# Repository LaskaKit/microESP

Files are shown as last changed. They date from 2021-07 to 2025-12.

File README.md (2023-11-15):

# LaskaKit microESP with ESP32-C3

An incredibly powerful yet miniature board - microESP with the latest ESP32-C3 chip in the ESP32-C3-MINI module supporting Wi-Fi and Bluetooth connectivity and also has very low power consumption.

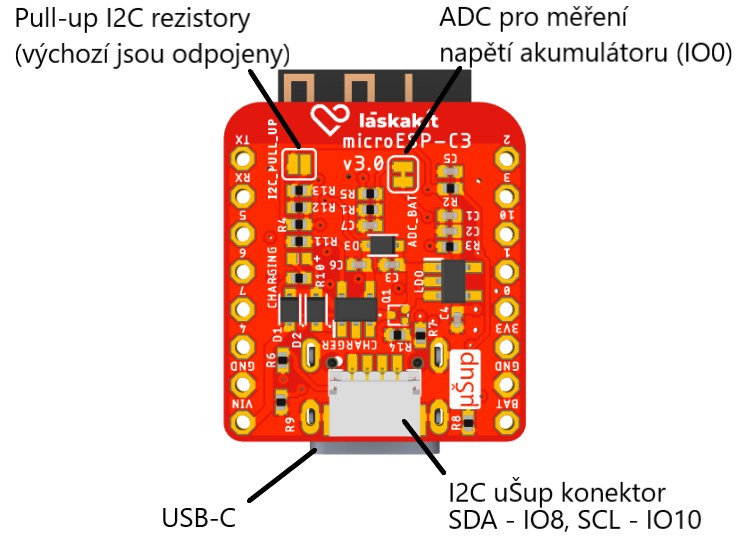
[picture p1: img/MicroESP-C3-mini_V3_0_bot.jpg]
Popis microESP_ESP32-C3_BOTTOM.jpg


PINOUT

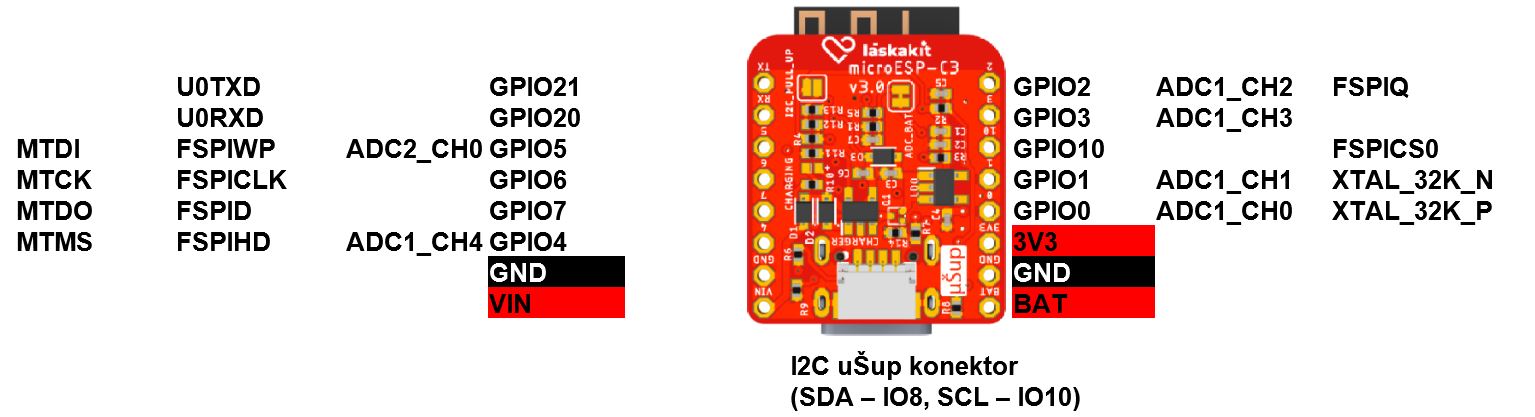
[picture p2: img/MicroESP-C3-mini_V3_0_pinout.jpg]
Pinout


As you can see above, the board includes a lot of things. Let's describe the boardy in details. 
The board is powered from Li-Pol battery what is charger through li-pol charger from solar panel. The recommended voltage of solar panel shall be 5V or 6V.

We put our versatile and safe μŠup connector where you can connect I2C sensors. The lock of connector is mounted inside the connector, so no worries, you can not damage the sensor because you can not turn over the connector.
The sensor what are useful for this board are [SHT40 (temperature and humidity)](https://www.laskakit.cz/laskakit-sht40-senzor-teploty-a-vlhkosti-vzduchu/) or [SCD41 (CO2, temperature, humidity](https://www.laskakit.cz/laskakit-scd41-senzor-co2--teploty-a-vlhkosti-vzduchu/). 
Moreover, we added GPIOs on both sides of board what you can use for what you want.

On the upper side, there are two solder bridges. First solder bridge is used for enabling of voltage measurement from battery. 
One is battery voltage measurement (connected to IO0) and the maximum input voltage is 5.8V (with 3.3V ADC reference voltage, R1 1M, R2 1.3M). 
The second solder bridge is used for connecting of I2C pull up resistors (SDA - IO8, SCL - IO10) to power supply (3.3V).

To program this miniature and very economical board, you need to connect a USB-C cable to your computer and switch the ESP32-C3 to bootloader mode with the following trick.
Connect the USB-C to the microESP and the computer.
Press and hold the FLASH button.
Press and release the RESET button.
Release the FLASH button.

This board is available on https://www.laskakit.cz/laskakit-microesp/

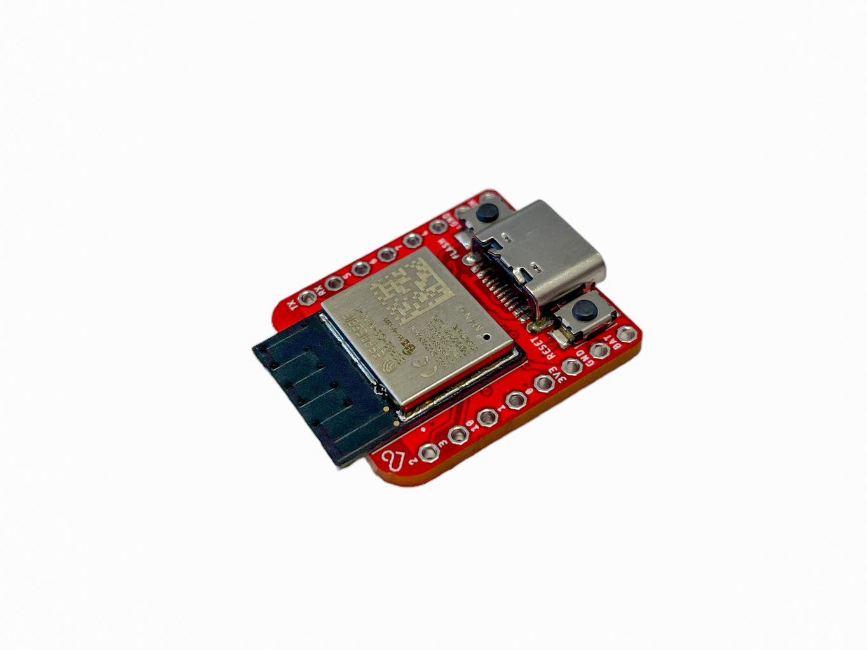
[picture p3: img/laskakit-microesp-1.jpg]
TOP

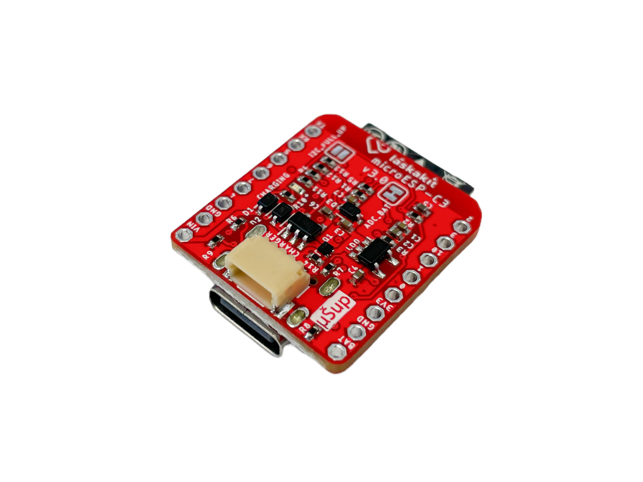
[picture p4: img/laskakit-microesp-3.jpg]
BOTTOM


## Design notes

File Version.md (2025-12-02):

### Version 3.2
- Fixed wrong IO number on top silkscreen, IO8 was "1"
#### Version 3.1
- LDO replaced for RT9080
- µŠup konnector moved a little bit inside
- I2C pullups deleted
- Some power optimisation
- LED Added on GPIO 4
#### Version 3.0
- Reworked version with new module ESP32-C3-MINI
#### Version 2.1
Adjusted resistor values in the resistance divider to 1M/1.3M, ADC max. input voltage stays the same.| Upraveny hodnoty rezistorů v odporovém děliči na 1M/1.3M, ADC max. vstupní napětí zůstává stejné.
#### Version 2.0
- Change ESP-12 to ESP32-C3 | Změněn modul ESP-12 na ESP32-C3
- Voltager devider GPIIO0 (Bat_ADC) changed to 100k/130k ADC max. input voltage is 4.335 V | Dělič napětí GPIIO0 (Bat_ADC) změněn na 100k/130k ADC max. vstupní napětí je 4.335 V
- Voltager devider GPIIO1 (Solar_ADC) changed to 1M/330k ADC max. input voltage is 9.874 V | Dělič napětí GPIIO1 (Solar_ADC) změněn na 1M/330k ADC max. vstupní napětí je 9.874 V
- Add 100nF capacitors to ADC inputs Bat_ADC and Solar_ADC | Přidány filtrační kondenzátory 100nF na ADC vstupy Bat_ADC a Solar_ADC
#### Version 1.0
- Initial | Počáteční

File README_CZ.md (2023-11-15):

# LaskaKit microESP s ESP32-C3

Neskutečně nabušená a přitom miniaturní deska - microESP s nejnovějším čipem ESP32-C3 v modulu ESP32-C3-MINI podporující Wi-Fi i Bluetooth konektivitu a navíc má i velmi malou vlastní spotřebu. 

Popis microESP_ESP32-C3_BOTTOM.jpg

PINOUT

Pinout

Jak můžeš vidět na obrázku výše, na desce je toho opravdu hodně. Deska se napájí z připojeného akumulátoru, který může být nabíjen přes integrovaný nabíjecí kontrolér ze solárního panelu. Jmenovité napětí solárního panelu doporučujeme 5V nebo 6V. 

Na desku jsme přidali i náš μŠup konektor, ke kterému můžeš velmi pohodlně a bezpečně připojit nejrůznější I2C čidla. Konektor zajišťuje bezpečnost připojení díky vestavěnému zámku v konektoru. 
Čidla, která se hodí k této vývojové desce jsou například [SHT40 (čidlo teploty a vlhkosti)](https://www.laskakit.cz/laskakit-sht40-senzor-teploty-a-vlhkosti-vzduchu/) nebo [SCD41 (čidlo CO2, teploty, vlhkosti](https://www.laskakit.cz/laskakit-scd41-senzor-co2--teploty-a-vlhkosti-vzduchu/). 
Ale i přesto, že jsme tam dali konektor na I2C čidlo, využili jsme prostor ještě k přidání dalších GPIO po stranách modulu.
Vyvedli jsme i RX a TX sběrnice UART, takže pokud máš nějaké čidlo komunikující skrze UART, není problém ho s microESP použít. 

Na horní straně se ještě nachází dva pájecí mosty. Jeden je určený pro měření napětí akumulátoru (výstup za děličem napětí akumulátoru je připojen na IO0). Rezistor R1 je 1M, R2 je 1.3M, maximální vstupní napětí (při 3,3V ADC referenci) je 5,8V. 
Poslední pájecí most je připojení pull-up rezistorů na I2C sběrnici (SDA - IO8, SCL - IO10).

K programování této miniaturní a velmi úsporné desky potřebuješ připojit USB-C kabel k počítači a přepnout ESP32-C3 do bootloader režimu, což provedeš následujícím trikem.
Připoj USB-C do microESP a počítače.
Zmáčkni a drž tlačítko FLASH.
Zmáčkni a uvolni tlačítko RESET.
Uvolni tlačítko FLASH.

Tato deska je dostupná na https://www.laskakit.cz/laskakit-microesp/

TOP
BOTTOM

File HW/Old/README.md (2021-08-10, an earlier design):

# LaskaKit microESP

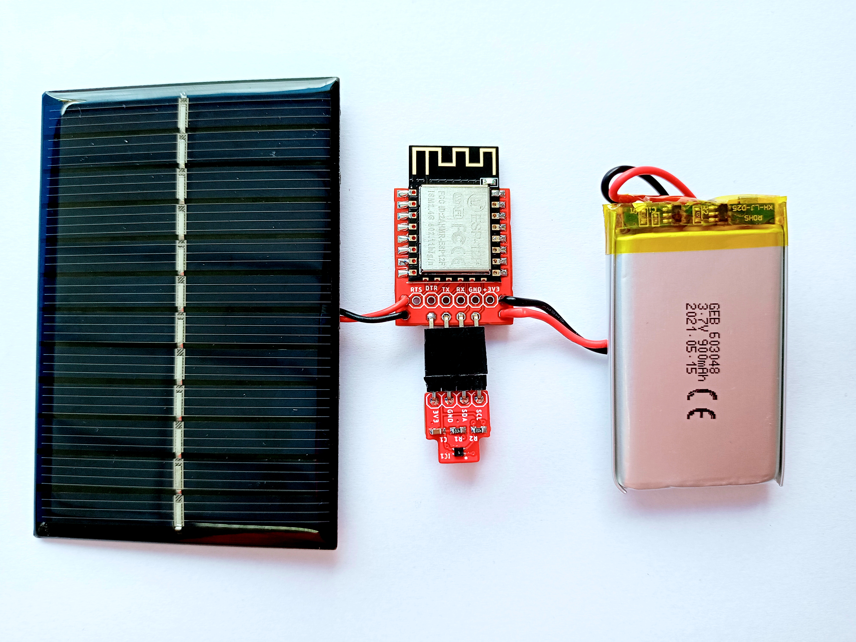
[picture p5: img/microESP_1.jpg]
microESP with solar panel


We would like to introduce the smallest evaluation board - [LaskaKit microESP](https://www.laskarduino.cz/laskakit-microesp/). The footprint is compatible with ESP12 or ESP07. It depends on you what you prefer to assemble. 
The dimension of PCB is only 24x21.5mm and the weight is 4g. The evaluation board includes - input of Li-ion battery, charging IC, 3.3V regulator with low quiescent current, input for solar panel and also connector with I2C bus.

## Layout

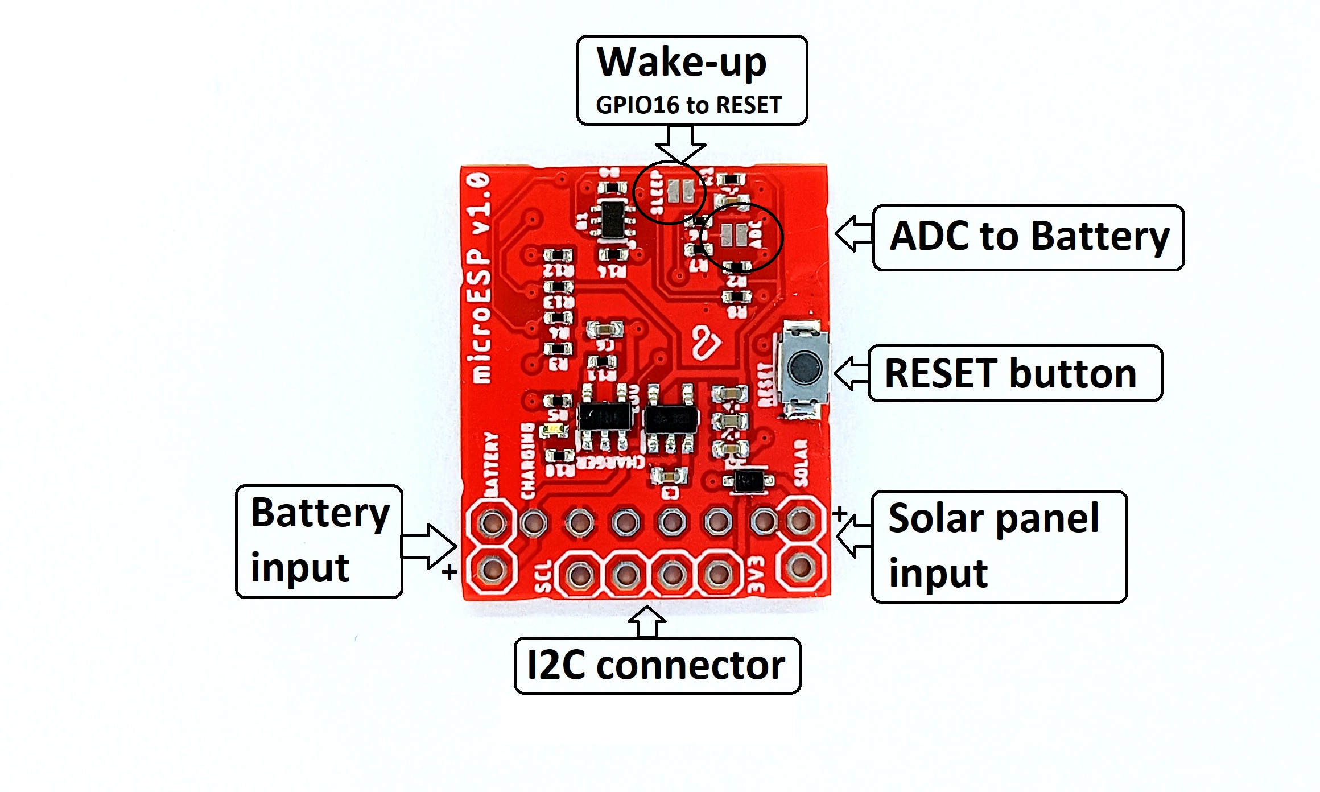
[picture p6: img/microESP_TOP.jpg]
TOP of microESP


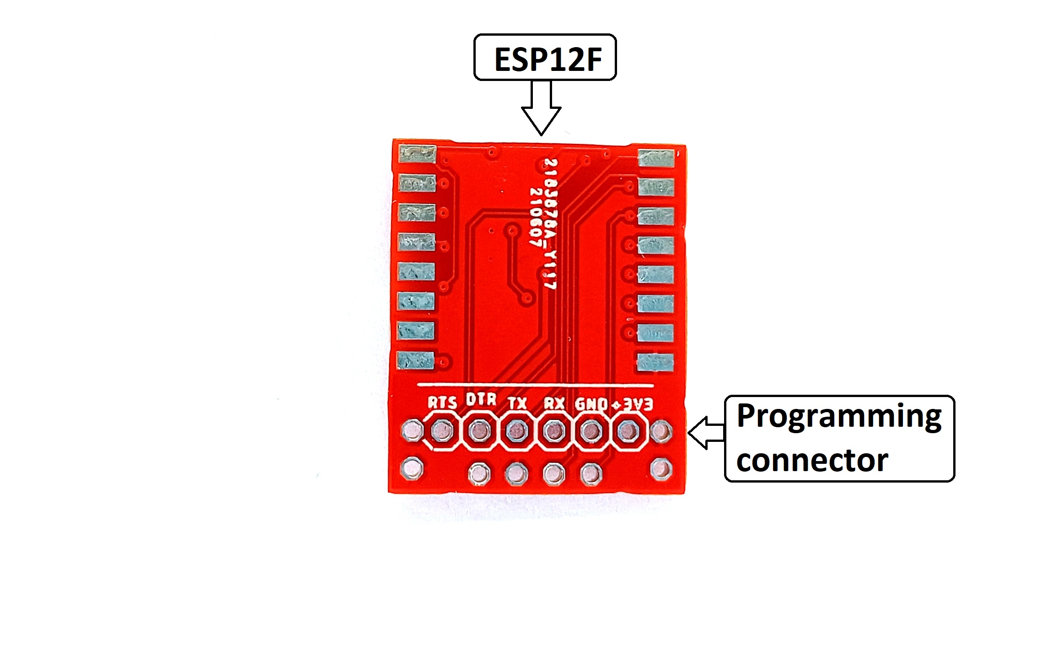
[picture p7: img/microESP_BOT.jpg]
BOTTOM of microESP


## Solar panel

The [TP4054](https://www.laskarduino.cz/toppower-tp4054-nabijecka-li-ion-clanku--0-4a--sot-23-5/) is used as charging IC, the maximum input voltaga is 10V hence the nominal voltage of solar panel shall be 5V, maximum 6V.

The charging current is defined by R11 resistor and the current is set to 400 mA.

## 3.3V regulator

We used HT7833 as main 3.3V regulator. The main advantage of this regulator is very low quiescentcurrent, typicaly 4 uA. 
Thanks to this regulator and the design of board, the overall current in deepsleep is only 22 uA.

## Programmer

We have own USB-UART programmer with CH340 IC, [LaskaKit CH340 programmer](https://www.laskarduino.cz/laskakit-ch340-programmer-usb-c--microusb--uart/). You can connect this programmer to your laptop through microUSB or USB-C cabel. 
The pinout of programmer is compatible with microESP. The programmer automatically switches the ESP8266 to bootloader mode and after the uploading of code, the ESP is automatically reset. 

## Another features

[LaskaKit microESP](https://www.laskarduino.cz/laskakit-microesp/) contains I2C connector for our temperature/humidity SHT4x/SHT3x module, buti t is not necessary to use only our module. You may directly use for example this module with [SHT31 module](https://www.laskarduino.cz/senzor-teploty-a-vlhkosti-vzduchu-sht30/), and indirectly [sensor of pressure, temperature and humidity BME280](https://www.laskarduino.cz/arduino-senzor-tlaku--teploty-a-vlhkosti-bme280/), [infrared sensor MLX90615](https://www.laskarduino.cz/arduino-infracerveny-teplomer-mlx90615/) or [GY-21 HTU21D sensor of temperature and humidity](https://www.laskarduino.cz/gy-21-htu21d-senzor-teploty-a-vlhkosti/).

Moreover there are reset button, solder bridge between GPIO16 and reset (to enable the wake up from deepsleep) and also there is voltage divider what is connected to battery and ADC. 
The maximum measured voltage is 4.3V what is enough for measuring of Li-ion battery.

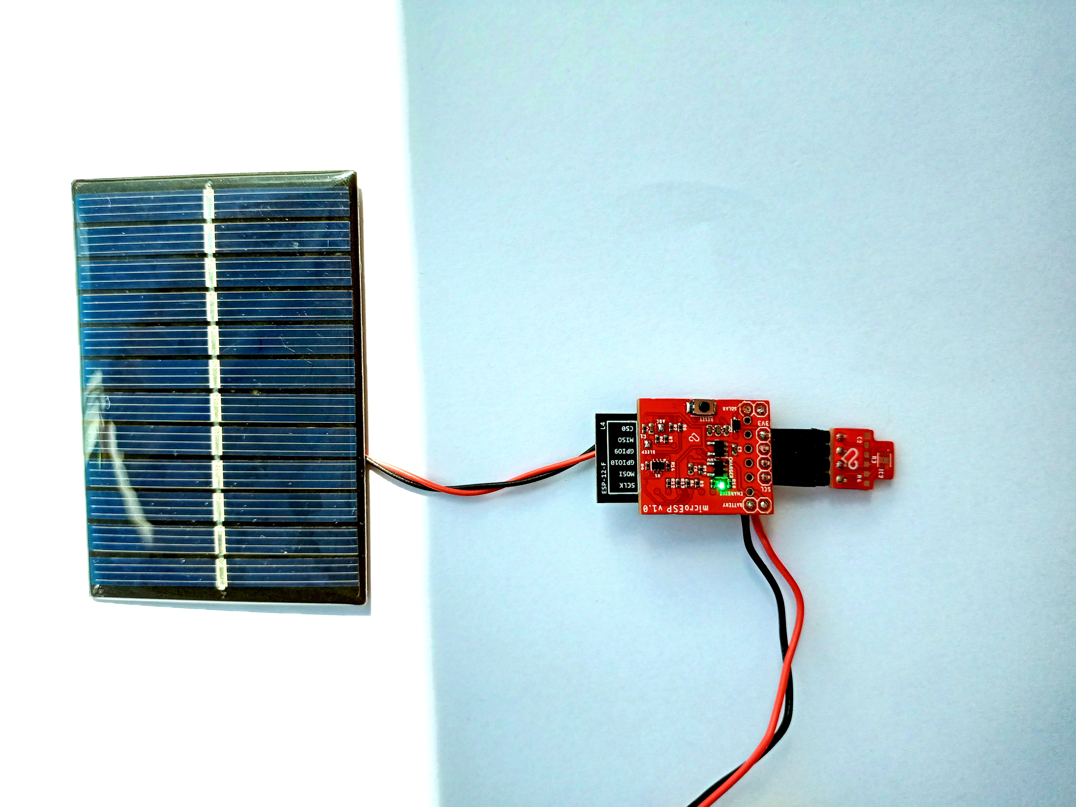
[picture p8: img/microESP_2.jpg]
microESP with solar panel


## Demo

We created a demo with our microESP, what you can see on the picture above.
The charging is indicated by LED on board, the sensor module [Temp-HumSensor-SHTxx](https://github.com/LaskaKit/Temp-HumSensor-SHTxx) may be directly connected to the main board. 

The example is available on [our github repository](https://github.com/LaskaKit/microESP/tree/main/examples). IN this example, ESP12 (which we soldered) reads the current temperature and humidity from SHT40 and send to Serial monitor.

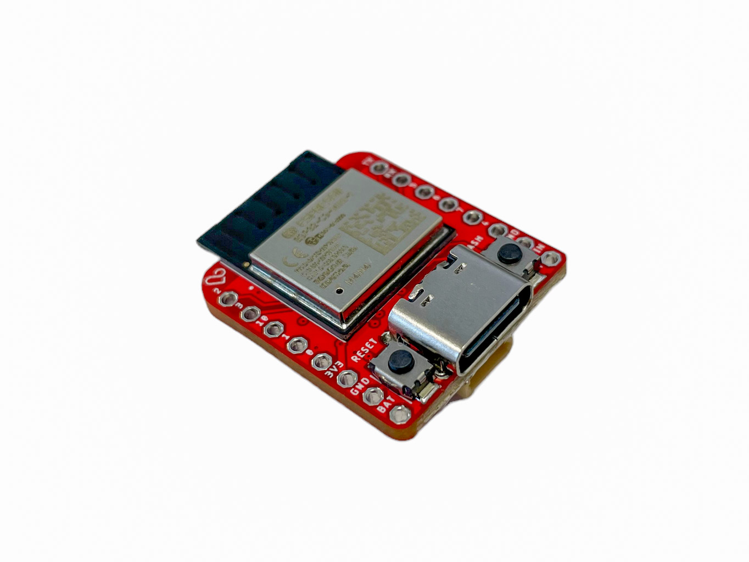
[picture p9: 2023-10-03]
img/laskakit-microesp-2.jpg

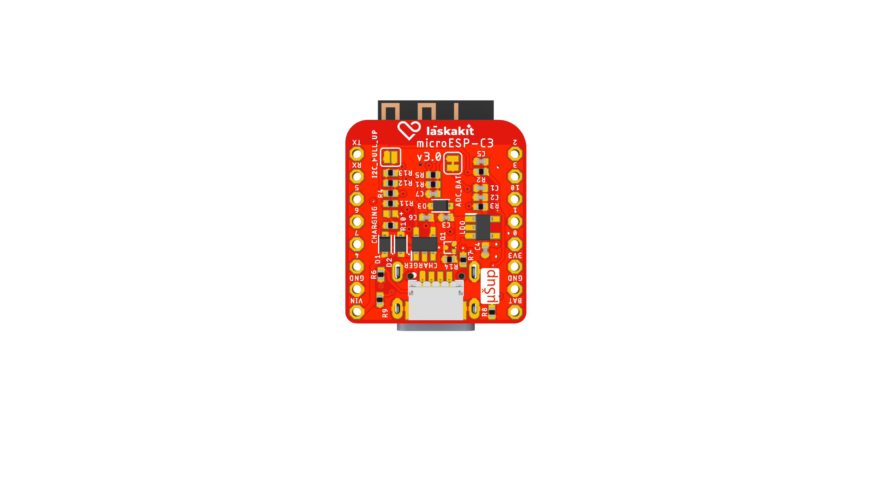
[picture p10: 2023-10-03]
img/MicroESP-C3-mini_back.png

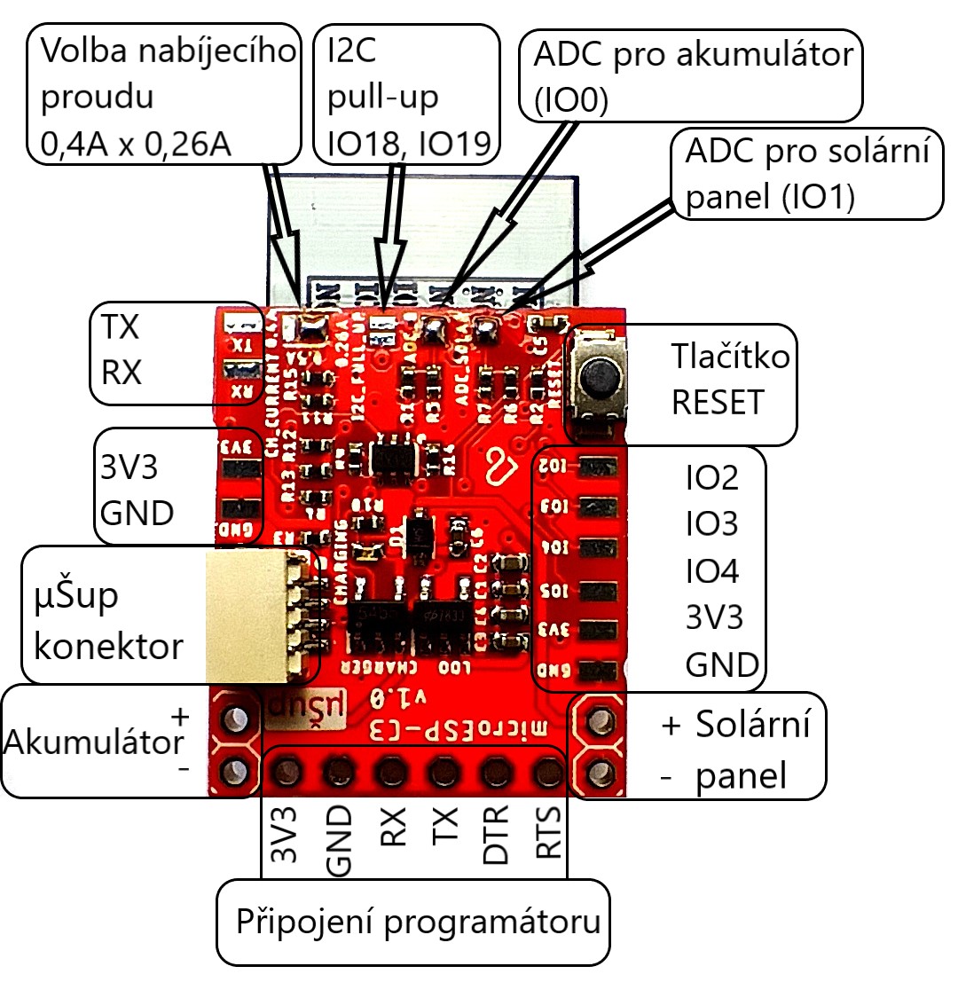
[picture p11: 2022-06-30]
img/microESP_ESP32-C3_BOTTOM.jpg

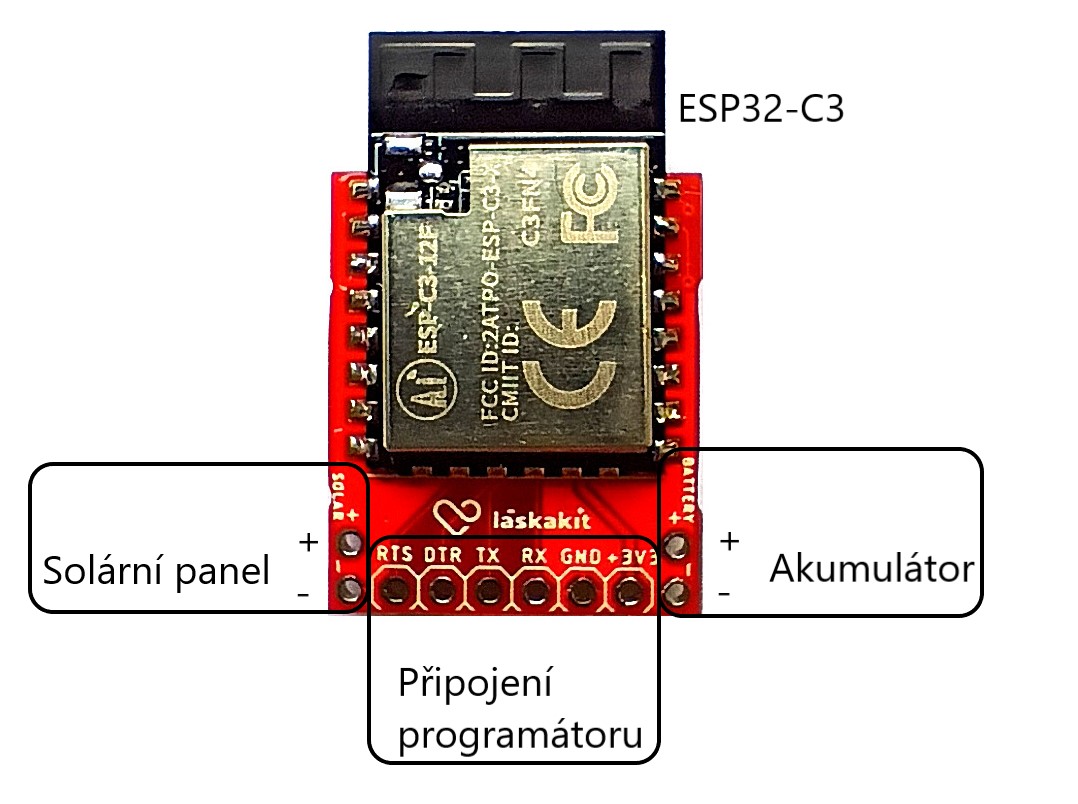
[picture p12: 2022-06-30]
img/microESP_ESP32-C3_TOP.jpg

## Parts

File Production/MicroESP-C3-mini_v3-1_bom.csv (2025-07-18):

Comment | Designator | Footprint | LCSC Part #
1.3M | R1 | R0402
1M | R5 | R0402
1k | R11 | R0402
1uF | C5 C6 | C0402
3.3k | R3 R10 | R0402
5k1 | R8 R9 | R0402
10k | R2 R4 R6 R7 | R0402
10uF/10V | C4 | C0402 | C106859
10uF/16V | C3 | C0402
22uF | C2 | C0402
100k | R14 | R0402
100nF | C1 C7 | C0402
AO3401 | Q1 | SOT-1215 | C547277
BAT60B | D2 D3 | SOD323-R | C514095
GREEN | LED | CHIPLED_0402
JST-SH_4p | J1 | 1X04_1MM_RA
JUMPER-SMT_2_NC_TRACE_SILK | ADC_BAT | SMT-JUMPER_2_NC_TRACE_SILK
RED | CHARGING | CHIPLED_0402
RT9080 | LDO | SOT94P280X100-5N
TP4054 | CHARGER | SOT-23-5
ESP32-C3-MINI-1-N4 | IC1 | ESP32C3MINI1N4
TS-1088R-02026 | FLASH RESET | TS1088R02026
USB-C_GT-USB-7010B | J2 | G-SWITCH_GT-USB-7010B | C2837092

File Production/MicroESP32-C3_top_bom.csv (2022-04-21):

Comment | Designator | Footprint | LCSC Part #
1k65 | R11 | R0402
1uF | C3 C6 | C0402
3k3 | R15 | R0402
4 7uF | C4 | C0402 | C106859
10k | R2 R3 R4 R9 R12 R13 R14 | R0402
10uF | C2 | C0402
100k | R5 | R0402
100nF | C1 C5 | C0402
330 | R10 | R0402
330k | R1 R7 | R0402
680k | R6 | R0402 | C4131
BAT60B | D1 | SOD323-R
HT7833 | LDO | SOT23-5
MMDT3904 | Q1 | SC70-6 | C268586
RED | CHARGING | CHIPLED_0402
TP4054 | CHARGER | SOT-23-5
TS-1088R-02026 | RESET | TS1088R02026
4p | J1 | 4p | C145956

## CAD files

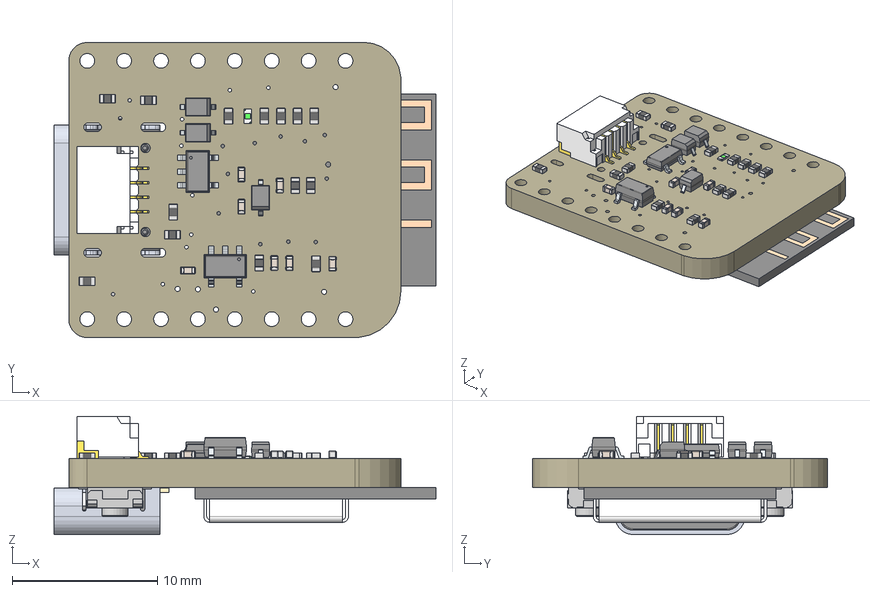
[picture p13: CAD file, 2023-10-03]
3D/MicroESP-C3-mini_v3.step
26.3 x 20.3 x 8.13 mm
Board
Pin1 x 7
Pin2 x 7
CeramicBody x 7
LASKAKIT_HEART_3MM
LASKKIT_10MM_SILKSCREEN
USUP_4MM_SILKSCREEN
1X04_1MM_RA
USBC_USB-C-16P-5
CHIPLED_0402
FilletPinL x 3
FilletPinR x 3
SOT-1215
ESP32C3MINI1N4
PinsArrayL
PinsArrayR
PinsArrayL (1)
PinsArrayR (1)
TS1088R02026 x 2
SMT-JUMPER_2_NC_TRACE_SILK
SMT-JUMPER_2_NO_SILK
R0402 x 14

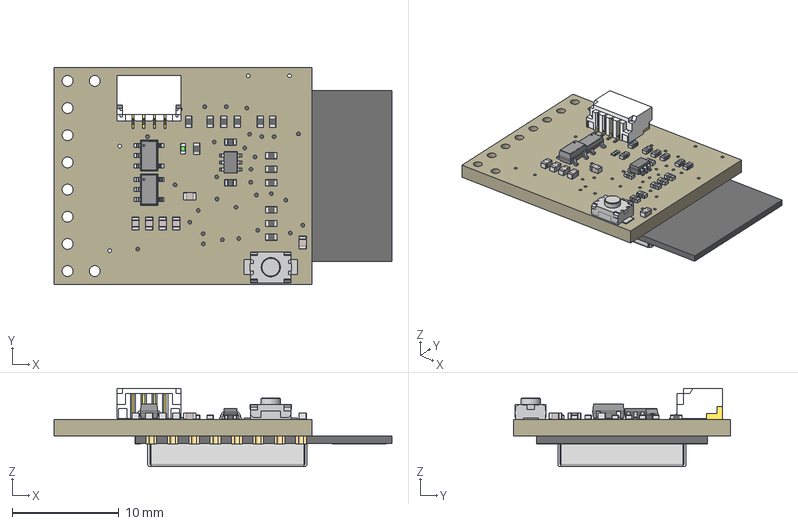
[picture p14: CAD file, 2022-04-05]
3D/MicroESP32-C3.step
31.6 x 20.3 x 7.32 mm
Board
LASKAKIT_HEART_3MM
LASKKIT_10MM_SILKSCREEN
CHIPLED_0402
SC70-6
PIN2
PIN 1
ANT
Surface 4
Surface 5
Surface 1
Surface 2
Surface 3
CAN
PCB
PinsArrayL
PinsArrayR
PinsArrayL (1)
PinsArrayR (1)
TS1088R02026
C0402 x 6
R0402 x 15
USUP_4MM_SILKSCREEN
1X04_1MM_RA

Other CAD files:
3D/MicroESP-C3-mini v3.f3d
3D/old/MicroESP-C3-mini v3.f3d

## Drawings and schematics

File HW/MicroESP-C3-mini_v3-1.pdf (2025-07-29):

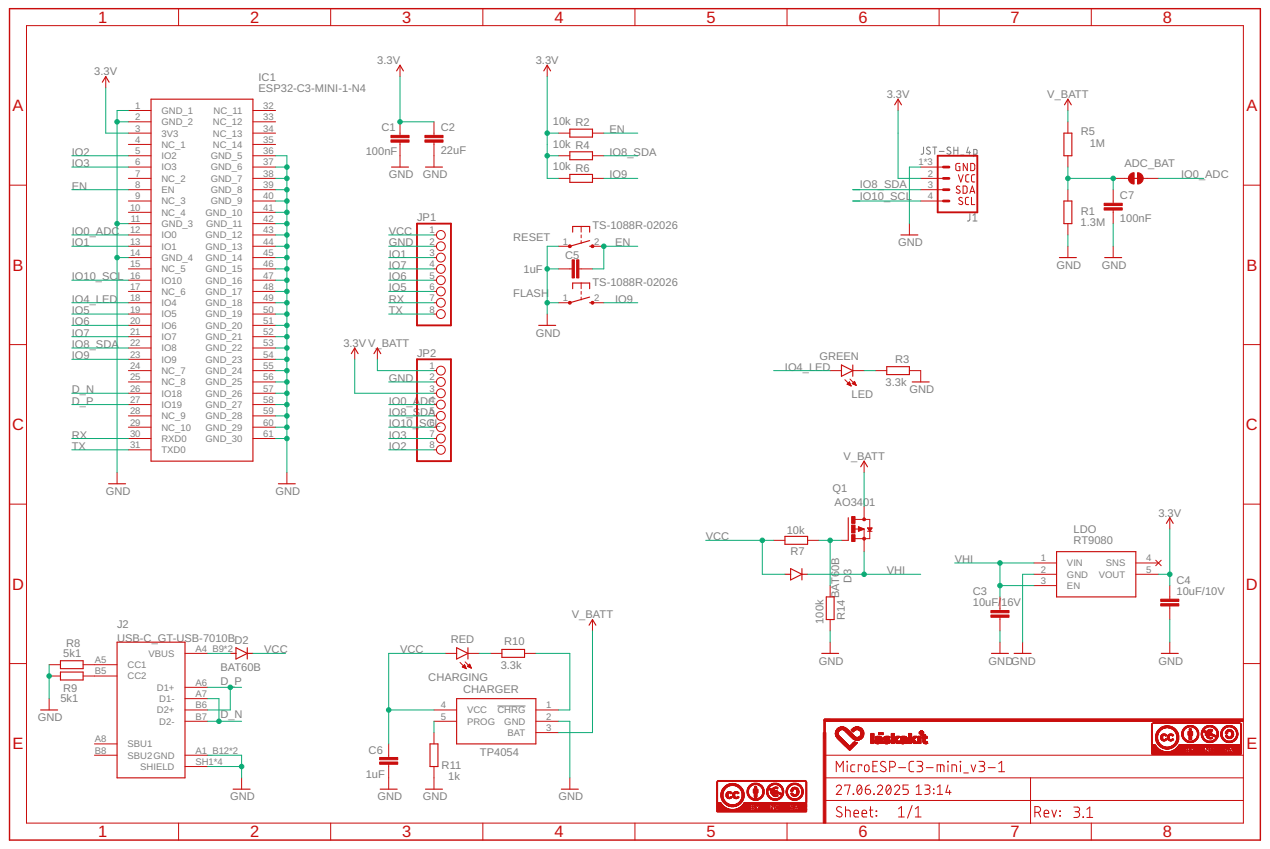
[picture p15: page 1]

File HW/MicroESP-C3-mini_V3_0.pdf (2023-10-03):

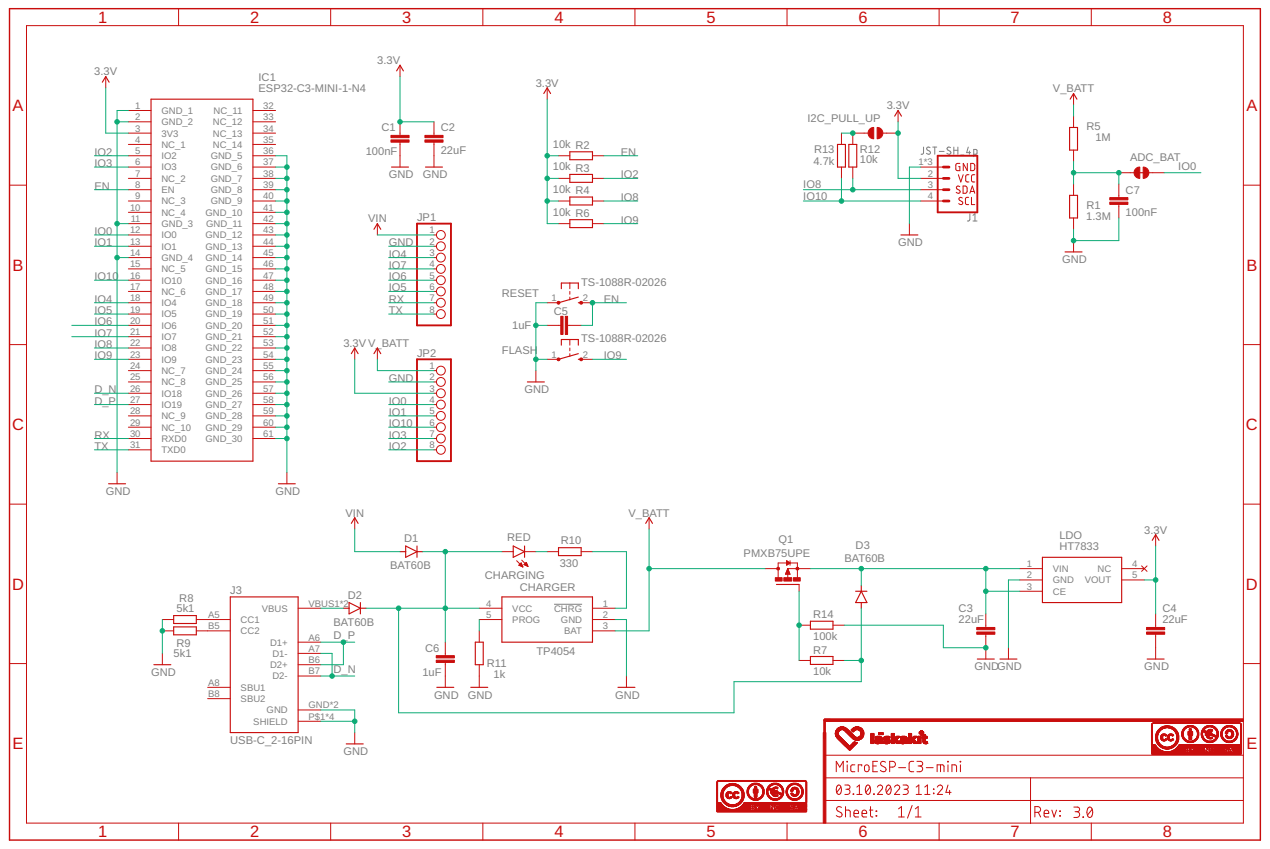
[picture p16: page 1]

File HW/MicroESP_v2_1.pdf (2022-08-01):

A

A

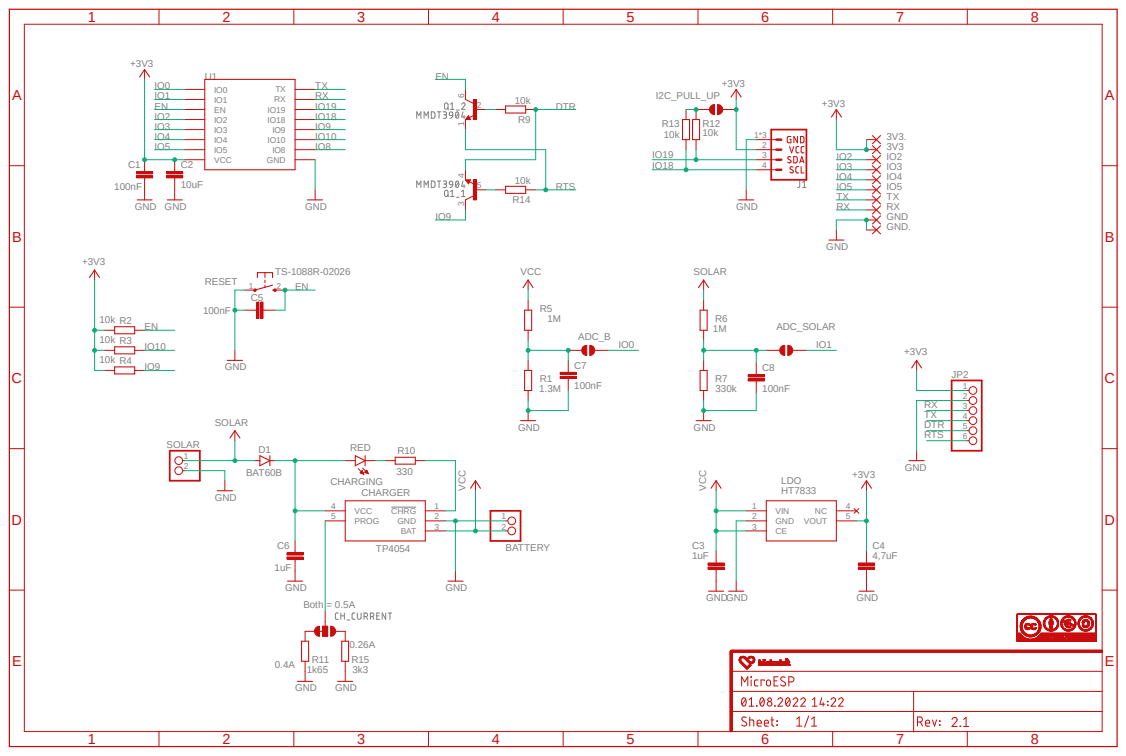
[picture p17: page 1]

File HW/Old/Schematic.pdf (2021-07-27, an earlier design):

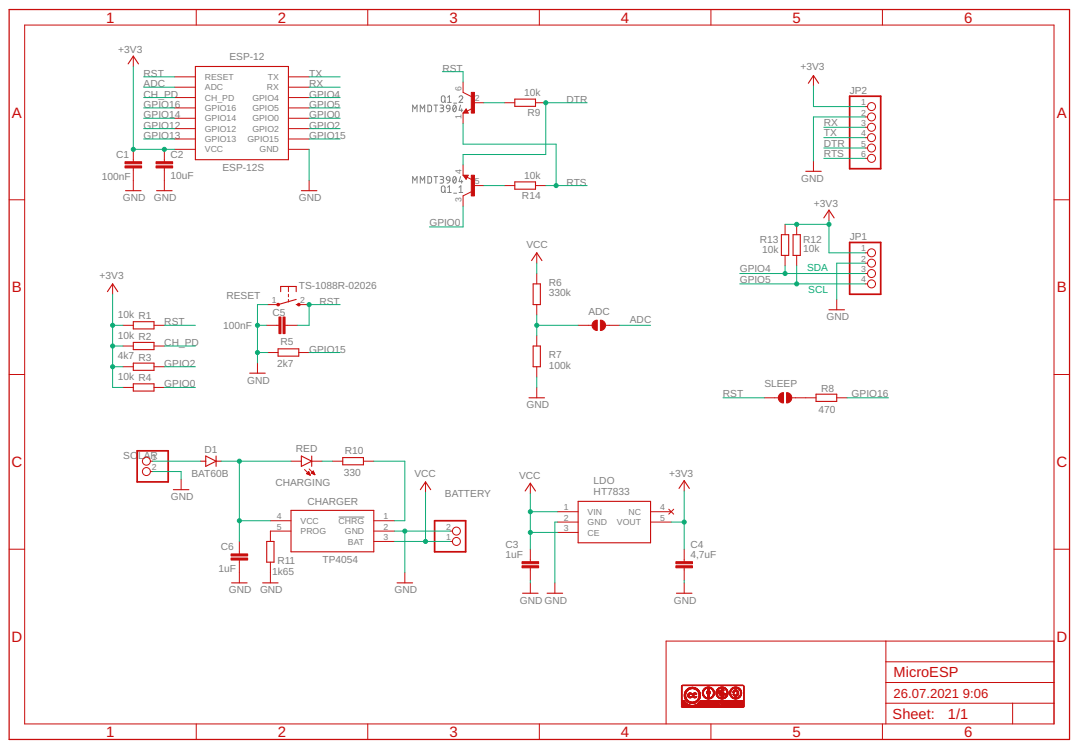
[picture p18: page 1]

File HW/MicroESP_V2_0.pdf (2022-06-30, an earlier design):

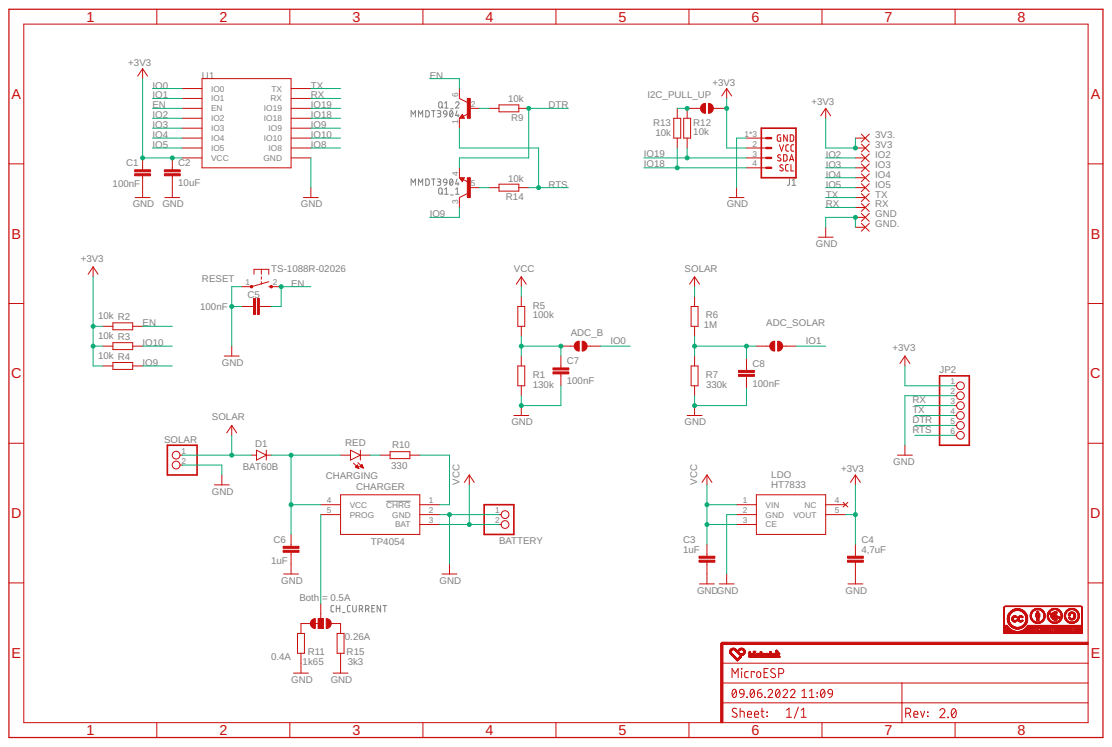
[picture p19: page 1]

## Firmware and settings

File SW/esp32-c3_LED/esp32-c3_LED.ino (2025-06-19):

/* LaskaKit LaskaKit ESP32-C3-LPKit blink example.
 * 
 * Board:   LaskaKit ESP32-C3-LPKit  https://www.laskakit.cz/laskkit-esp-12-board
 * 
 * In Arduino IDE choose board: "ESP32C3 Dev Module"
 * 
 * Made by (c) laskakit.cz 2025
 * Email:podpora@laskakit.cz
 * Web:laskakit.cz
 */

#define led 4           
int i, j;

void setup() {
  pinMode(led, OUTPUT);   
}

void loop() {
  for(i=0; i < 3; i++) {
    digitalWrite(led, HIGH);
    delay(100);

    digitalWrite(led, LOW);
    delay(100);
  }
  
  delay(500);
  
  for(i=0; i < 1; i++) {
	  for(j=0; j <= 256;){
		  analogWrite(led, j);
      delay(1);
		  j += 1;
	  }
	  delay(500);
	  for(j=256; j >= 0;){
		  analogWrite(led, j);
      delay(1);
		  j -= 1;
	  }
    delay(500);
  }
  delay(500);
}

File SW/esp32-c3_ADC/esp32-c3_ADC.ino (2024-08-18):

/*
* This example code is used for LaskaKit microESP32-C3 board  https://www.laskakit.cz/laskakit-microesp/
*
* microESP32-C3 board reads voltage of Battery  
* and sends every 2 seconds through UART OR native USB of microESP32-C3 depends on settings, read below
*
* Made by (c) laskakit.cz 2024
* 
* !!! ESP library version !!!
* ESP32 library 3.0.x
* Condition: Tools -> if USB CDC On Boot is ENABLED then
* Serial means native USB
* Tools -> if USB CDC On Boot is DISABLED then
* Serial means UART
* ---
* ESP32 library 2.0.xy
* Condition: Tools -> USB CDC On Boot must be disabled
* use USBSerial to send data through native USB 
*
* Board: ESP32-C3 Dev Module
*/

#include <SPI.h>
#include <Wire.h>

#define ADCBpin 0
#define bDeviderRatio 1.7693877551  // Voltage devider ratio on ADC pin 1MOhm + 1.3MOhm

void setup() {
    
  Serial.begin(115200);
  delay(100); // let serial console settle
}

void loop() {

  float bat_voltage = analogReadMilliVolts(ADCBpin) * bDeviderRatio / 1000;
  Serial.print("Battery Voltage = " );
  Serial.print(bat_voltage);
  Serial.println("V");

  delay(2000);
}

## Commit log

2021-07-21 added schematic
2022-04-05 Update ESP to ESP32-C3
    [MicroESP32-C3.step, MicroESP32-C3_top_bom.csv, MicroESP_top_bom.csv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]
2022-04-21 test data
    [MicroESP32-C3_top_bom.csv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]
2022-04-27 data update
    [MicroESP32-C3_top_cpl.csv]
2022-06-30 see version.md
    [MicroESP_v2_0_top_bom.csv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]
2022-08-01 new version, see version.md
    [MicroESP_v2_0_top_bom.csv]
2022-08-22 ADC change
2022-09-27 schematic update
2023-06-21 new version
    [MicroESP-C3_bottom_bom.csv, MicroESP-C3_top_bom.csv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]
2024-08-02 Update esp32-c3_sht4x.ino
    USBSerial description
2024-08-02 Update esp32-c3_ADC_OLED.ino
    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
2024-08-02 Update esp32-c3_ADC.ino
    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
2024-08-11 Create esp32-c3_v3_sht4x.ino
    update for v3
2024-08-11 Update esp32-c3_ADC.ino
    ESP32 library version
2024-08-11 Update esp32-c3_ADC_OLED.ino
    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
2024-08-11 Delete SW/esp32-c3_ADC_OLED/esp32-c3_v3_ADC_OLED.ino
    delete
2024-08-11 Update esp32-c3_sht4x.ino
    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
2024-08-11 Delete SW/esp32-c3_sht4x/esp32-c3_v3_sht4x.ino
    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
2024-08-11 Update deepsleep_test.ino
    Serial bug fix
    [deepsleep_test.ino]
2024-08-11 Update esp32-c3_sht4x.ino
    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
    [esp32-c3_sht4x.ino]
2024-08-14 new ver
    [MicroESP-C3-mini v3.f3d, MicroESP-C3-mini_v3.step]
2024-08-18 "Fix ADC reading"
2025-06-19 new ver v 3.1 see version.md
    [MicroESP-C3-mini_v3-1_bom.csv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]
2025-07-18 folder change
    [MicroESP-C3-mini_v3-1_bom.csv, MicroESP-C3_top_bom.csv, MicroESP_v2_0_top_bom.csv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]
